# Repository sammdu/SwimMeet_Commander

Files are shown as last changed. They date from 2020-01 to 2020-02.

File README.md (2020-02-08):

# Swim Meet Commander

#### Unofficial macro keyboard for the [HY-TEK Swim Meet Manager](https://hytek.active.com/swim-meet-software.html) software.   

Designed with [KiCad](https://www.kicad-pcb.org/)   
Programmed with [Arduino](https://www.arduino.cc/)   

<a rel="license" href="https://www.oshwa.org/definition/">Open Source Hardware</a>
&nbsp;&nbsp;


## What Is This

A macro keyboard that controls the swim meet scoring software commonly used in American high-school and college swim meets. It simplifies operation of the software by pulling out 13 most used functionalities as dedicated keys, achieving one-key operation.

The device works by triggering keyboard shortcuts compatible with the swim meet software when a corresponding button is pushed. It is automatically recognized by most operating systems as an HID keyboard with no additional drivers required.

> 🔗 [See Technical Documentation on GitHub Wiki](https://github.com/sammdu/SwimMeet_Commander/wiki/Technical-Documentation)

## Assembled Device In-Operation

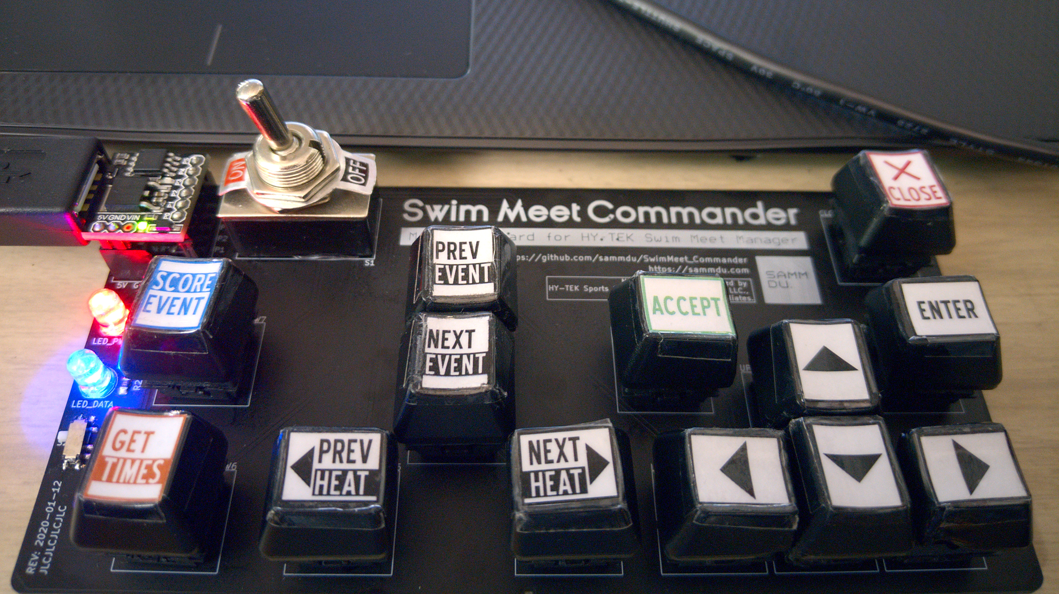
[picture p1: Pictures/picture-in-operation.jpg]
Assembled Device Picture


## 3D Renders

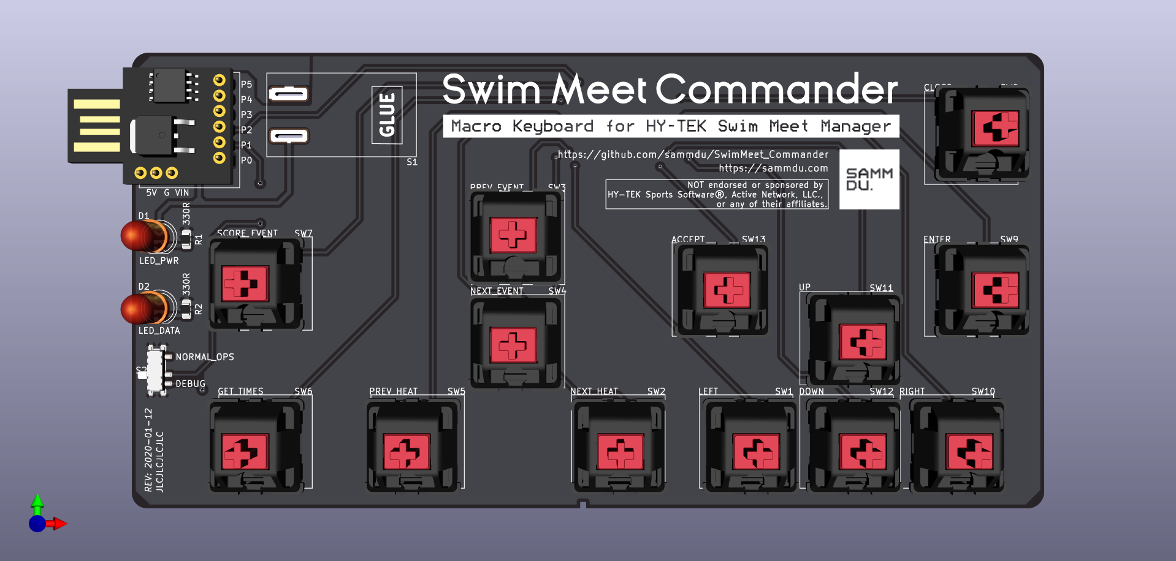
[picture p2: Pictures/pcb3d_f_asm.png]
PCB 3D Rendering, Front

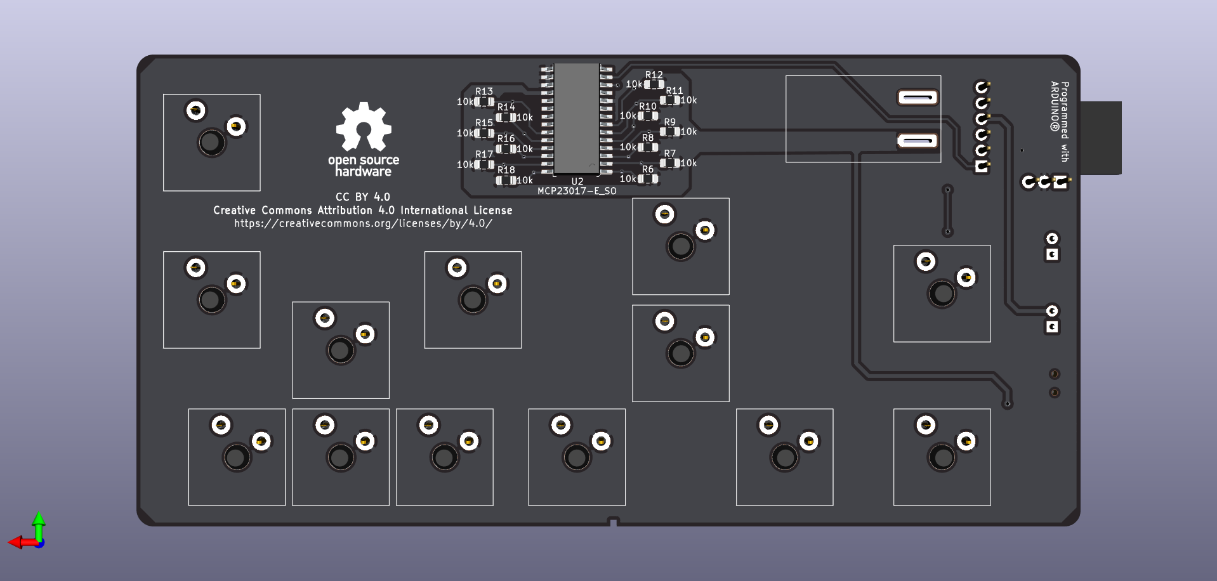
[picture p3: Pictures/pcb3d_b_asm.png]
PCB 3D Rendering, Back


## TODO

* adjust button spacing to account for keycaps

## Materials

* Microcontroller: Digispark Development Board - [Amazon Vendor](https://www.amazon.com/DAOKI-Digispark-Kickstarter-ATTINY85-Development/dp/B01MDUHSWO) | [Official Page (Out of Stock)](http://digistump.com/products/1)
* Printed Circuit Board (PCB) | [Get Gerber Production Files](https://github.com/sammdu/SwimMeet_Commander/tree/master/KiCad/Gerbers)
* I/O Expander (to support 13 switches simultaneously): [Microchip MCP23017](https://www.digikey.com/product-detail/en/MCP23017T-E%2fSO/MCP23017T-E%2fSOCT-ND/5358289/)
* Keyboard Switches: [E-Switch KS1100](https://www.digikey.com/product-detail/en/KS1100OA1AF060/EG5505-ND/7364301/)
* Key Caps: [Sparkfun PRT-15305](https://www.sparkfun.com/products/15305), or any Cherry MX compatible models   
* USB Male-Female Cable: [Qualtek 3021056-01M](https://www.digikey.com/product-detail/en/3021056-01M/Q1104-ND/7795306/), or any compatible USB Type-A cable   
* Toggle Switch: [Sparkfun COM-09276](https://www.sparkfun.com/products/9276)
* SMD Slide Switch: [Sparkfun COM-10860](https://www.sparkfun.com/products/10860), or any compatible models
* 5mm LEDs
* 0805 SMD Resistors: `330R`, `4k7` and `10k` values
* Pin Headers

## Copyright & Licensing

This project consists of open source software and hardware, released under [Creative Commons Attribution 4.0 International License](http://creativecommons.org/licenses/by/4.0/), unless otherwise specified.   

This project is NOT endorsed or sponsored by HY-TEK Sports Software®, Active Network, LLC., or any of their affiliates.

**NOTE:**
```
THE SCHEMATICS, DESIGN, SOURCE FILES, SOFTWARE, AND DATASHEETS ARE PROVIDED "AS IS",
WITHOUT WARRANTY OF ANY KIND, EXPRESS OR IMPLIED, INCLUDING BUT NOT LIMITED TO
THE WARRANTIES OF MERCHANTABILITY, FITNESS FOR A PARTICULAR PURPOSE AND
NONINFRINGEMENT. IN NO EVENT SHALL THE AUTHORS OR COPYRIGHT HOLDERS BE LIABLE FOR
ANY CLAIM, DAMAGES OR OTHER LIABILITY, WHETHER IN AN ACTION OF CONTRACT, TORT
OR OTHERWISE, ARISING FROM, OUT OF OR IN CONNECTION WITH THE SCHEMATICS, DESIGN,
SOURCE FILES, SOFTWARE, AND DATASHEETS OR THE USE OR OTHER DEALINGS IN THE
SCHEMATICS, DESIGN, SOURCE FILES, SOFTWARE, AND DATASHEETS.
 ```

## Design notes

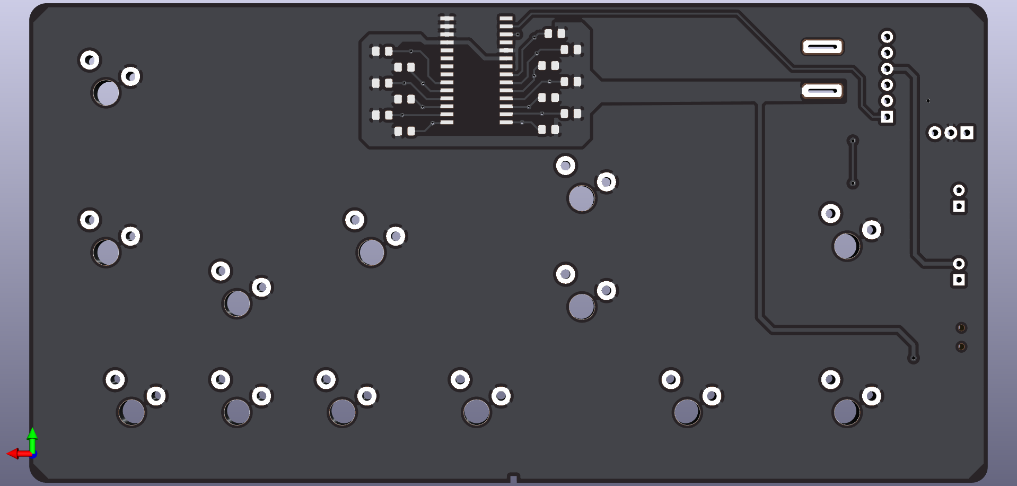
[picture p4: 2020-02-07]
Pictures/pcb3d_b_nosilk.png

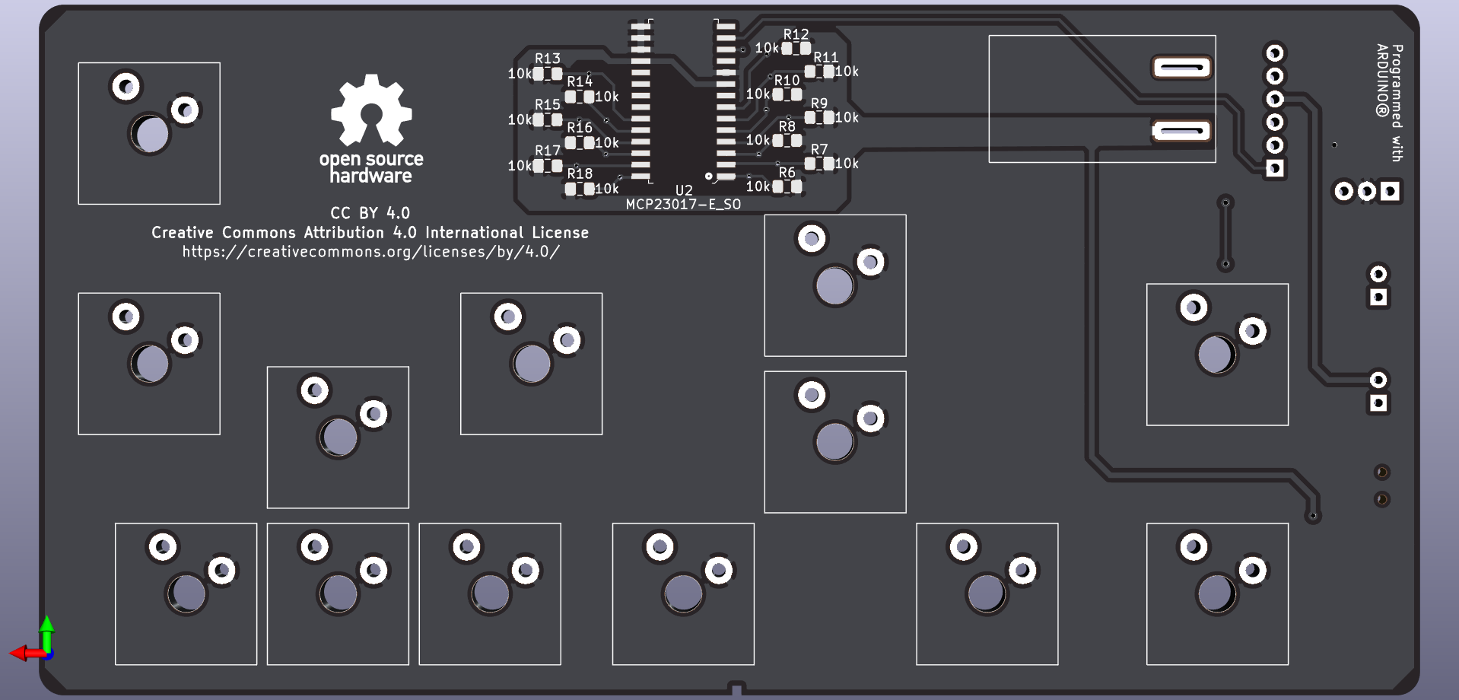
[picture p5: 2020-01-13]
Pictures/pcb3d_b.png

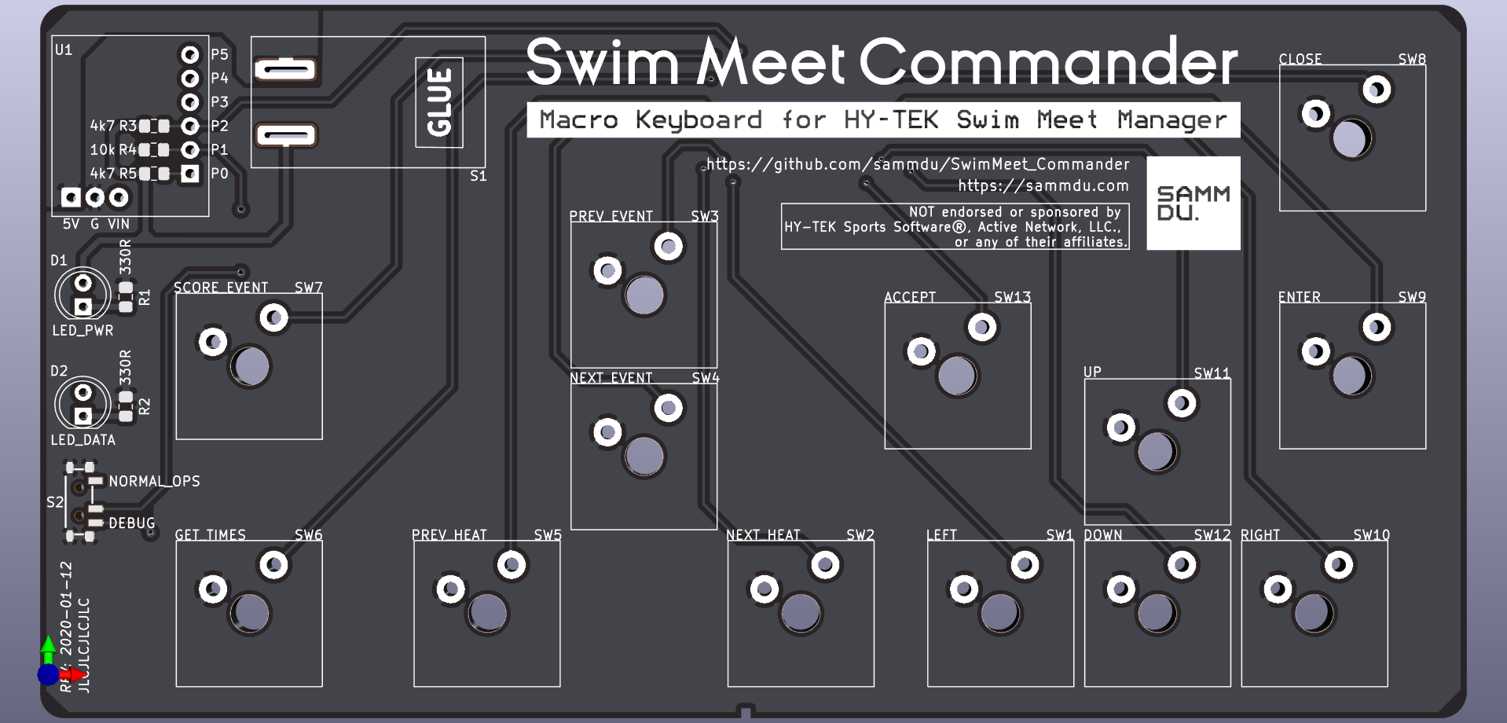
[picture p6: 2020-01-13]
Pictures/pcb3d_f.png

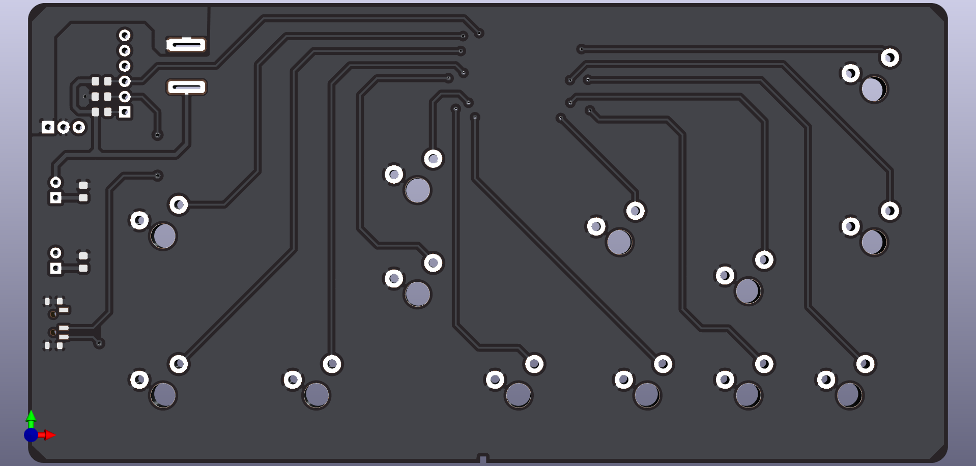
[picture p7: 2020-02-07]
Pictures/pcb3d_f_nosilk.png

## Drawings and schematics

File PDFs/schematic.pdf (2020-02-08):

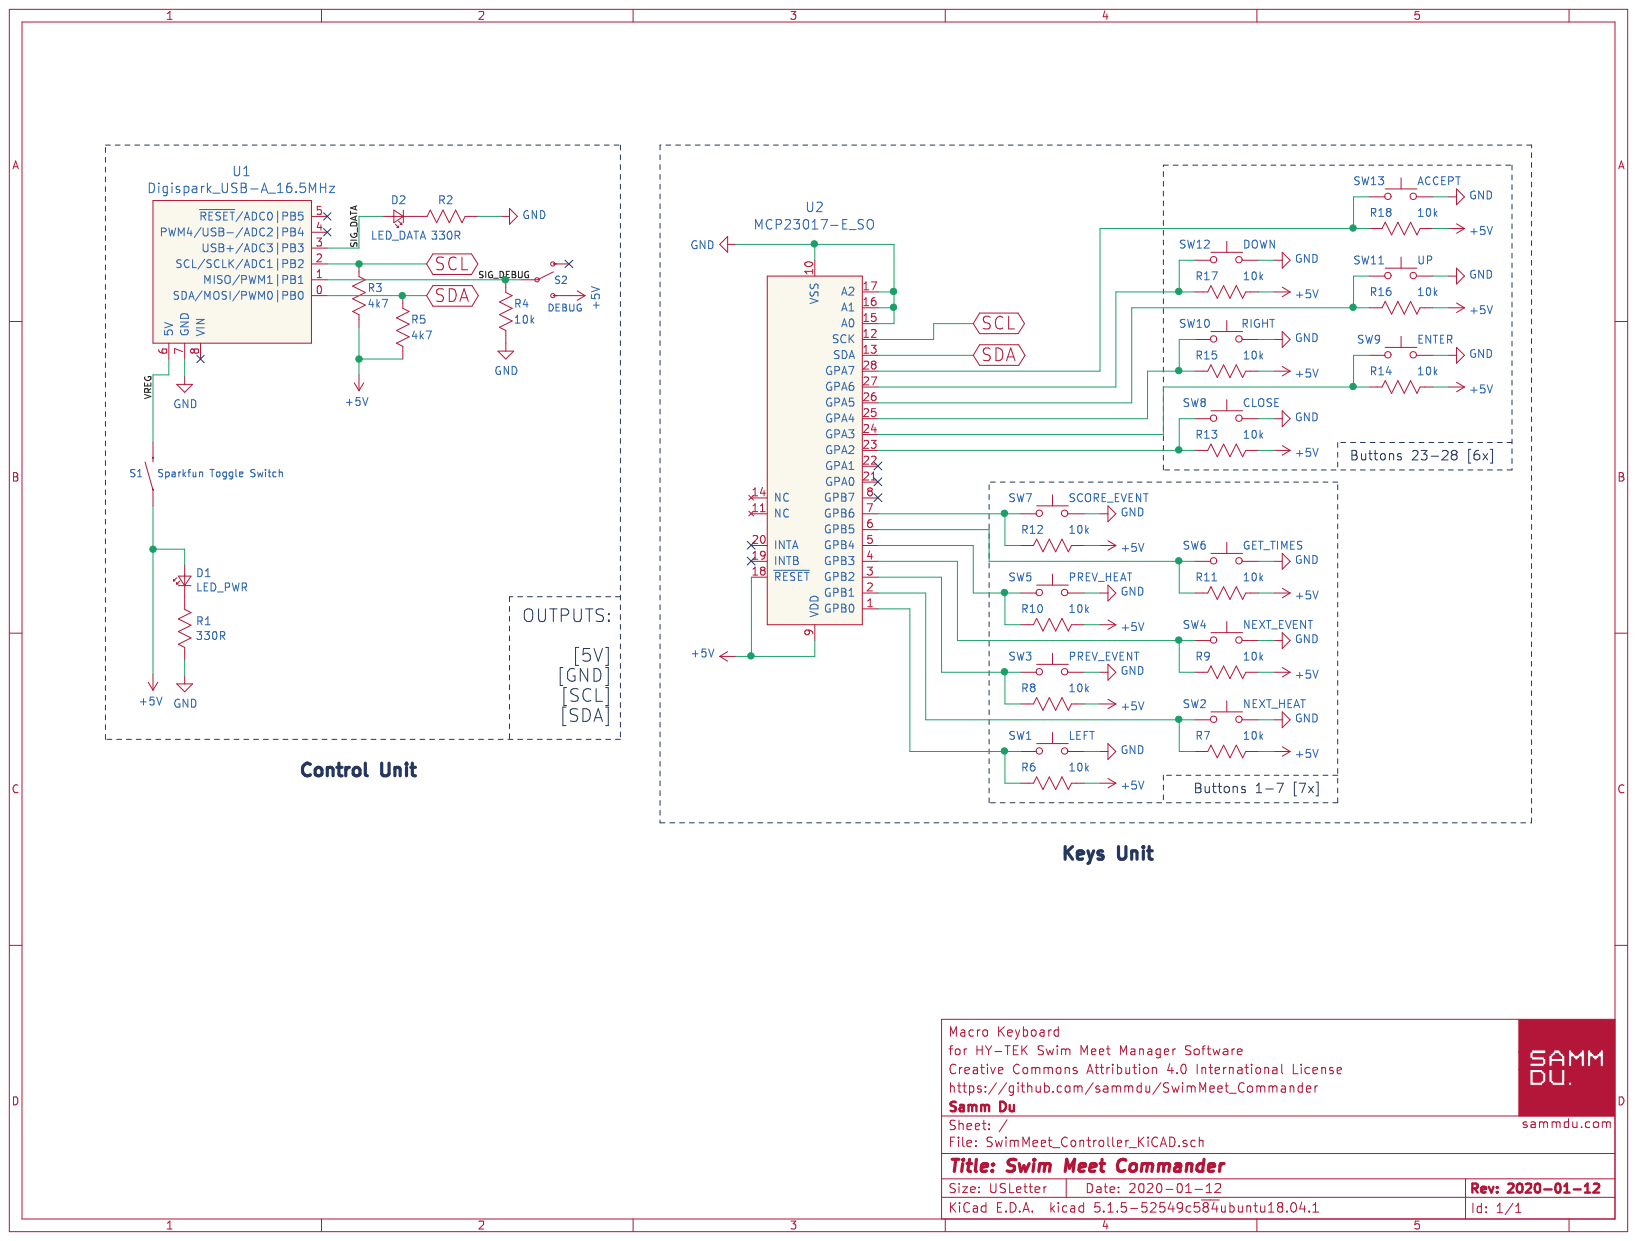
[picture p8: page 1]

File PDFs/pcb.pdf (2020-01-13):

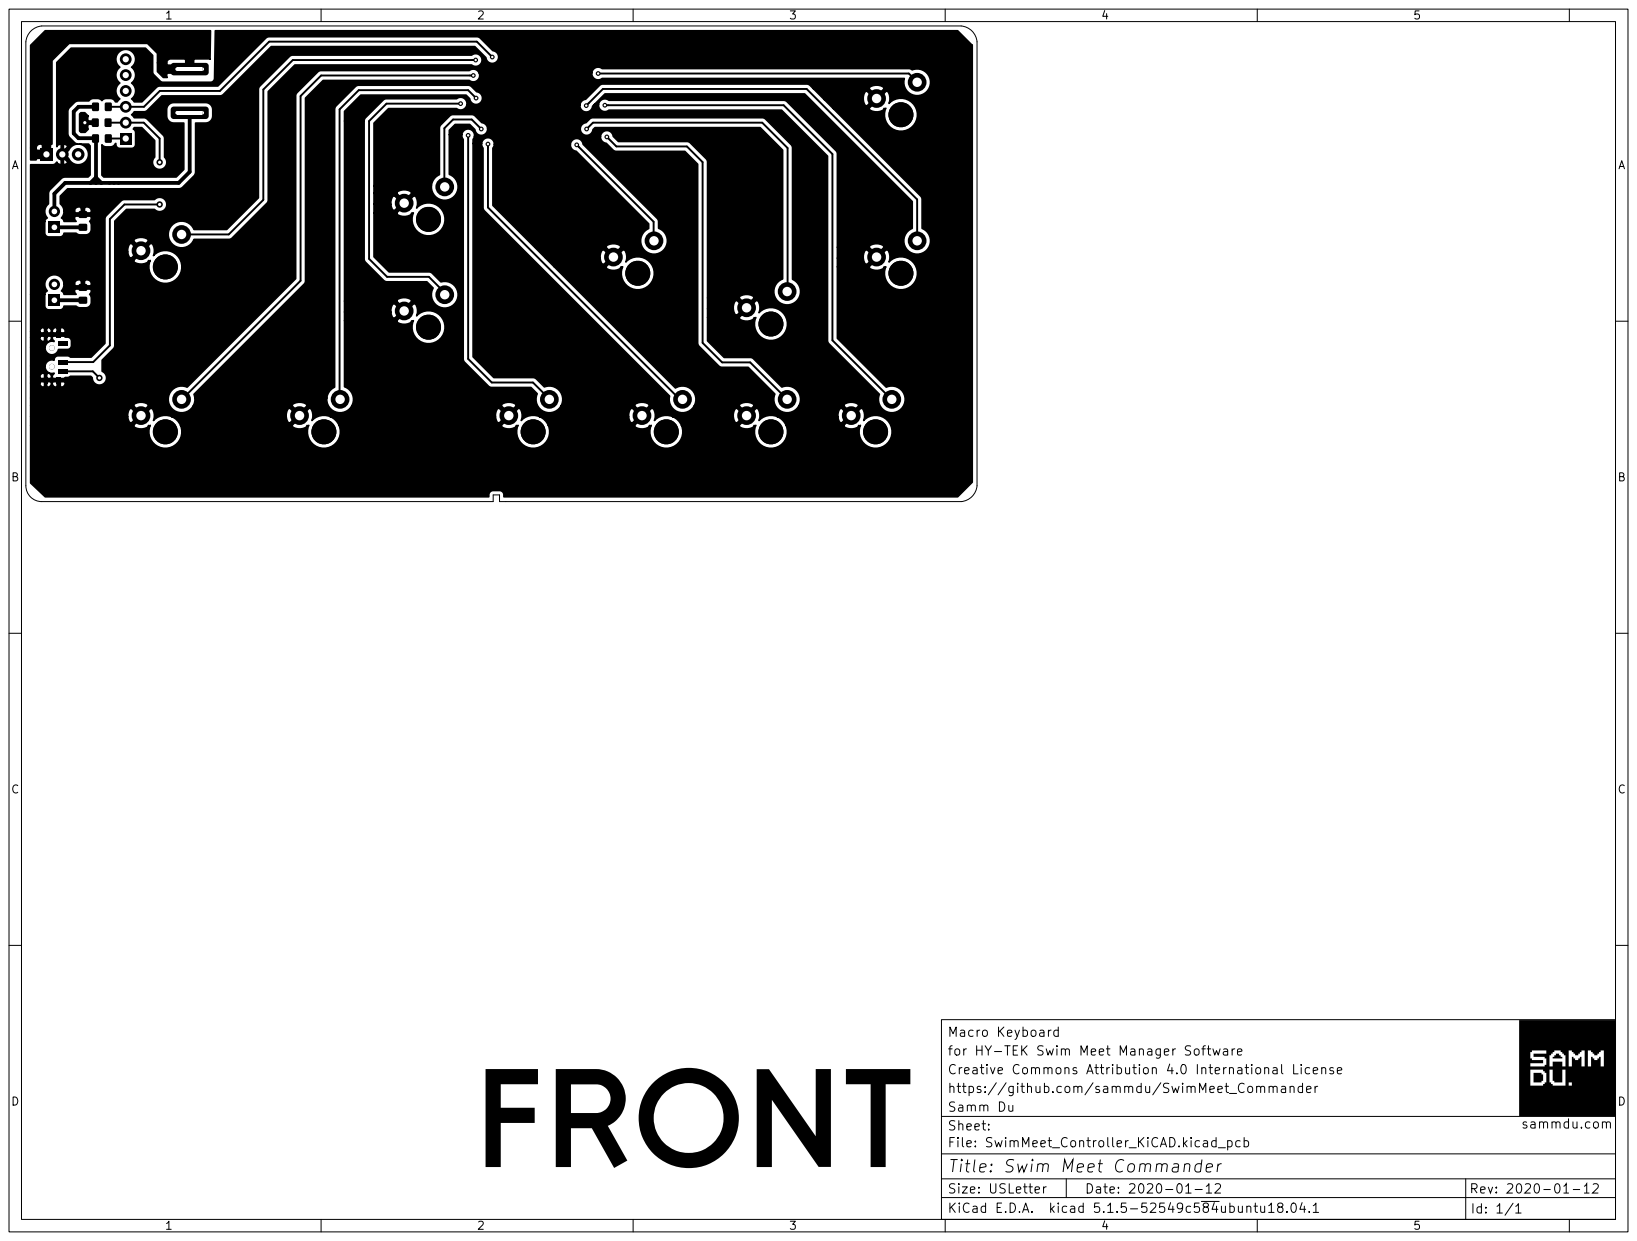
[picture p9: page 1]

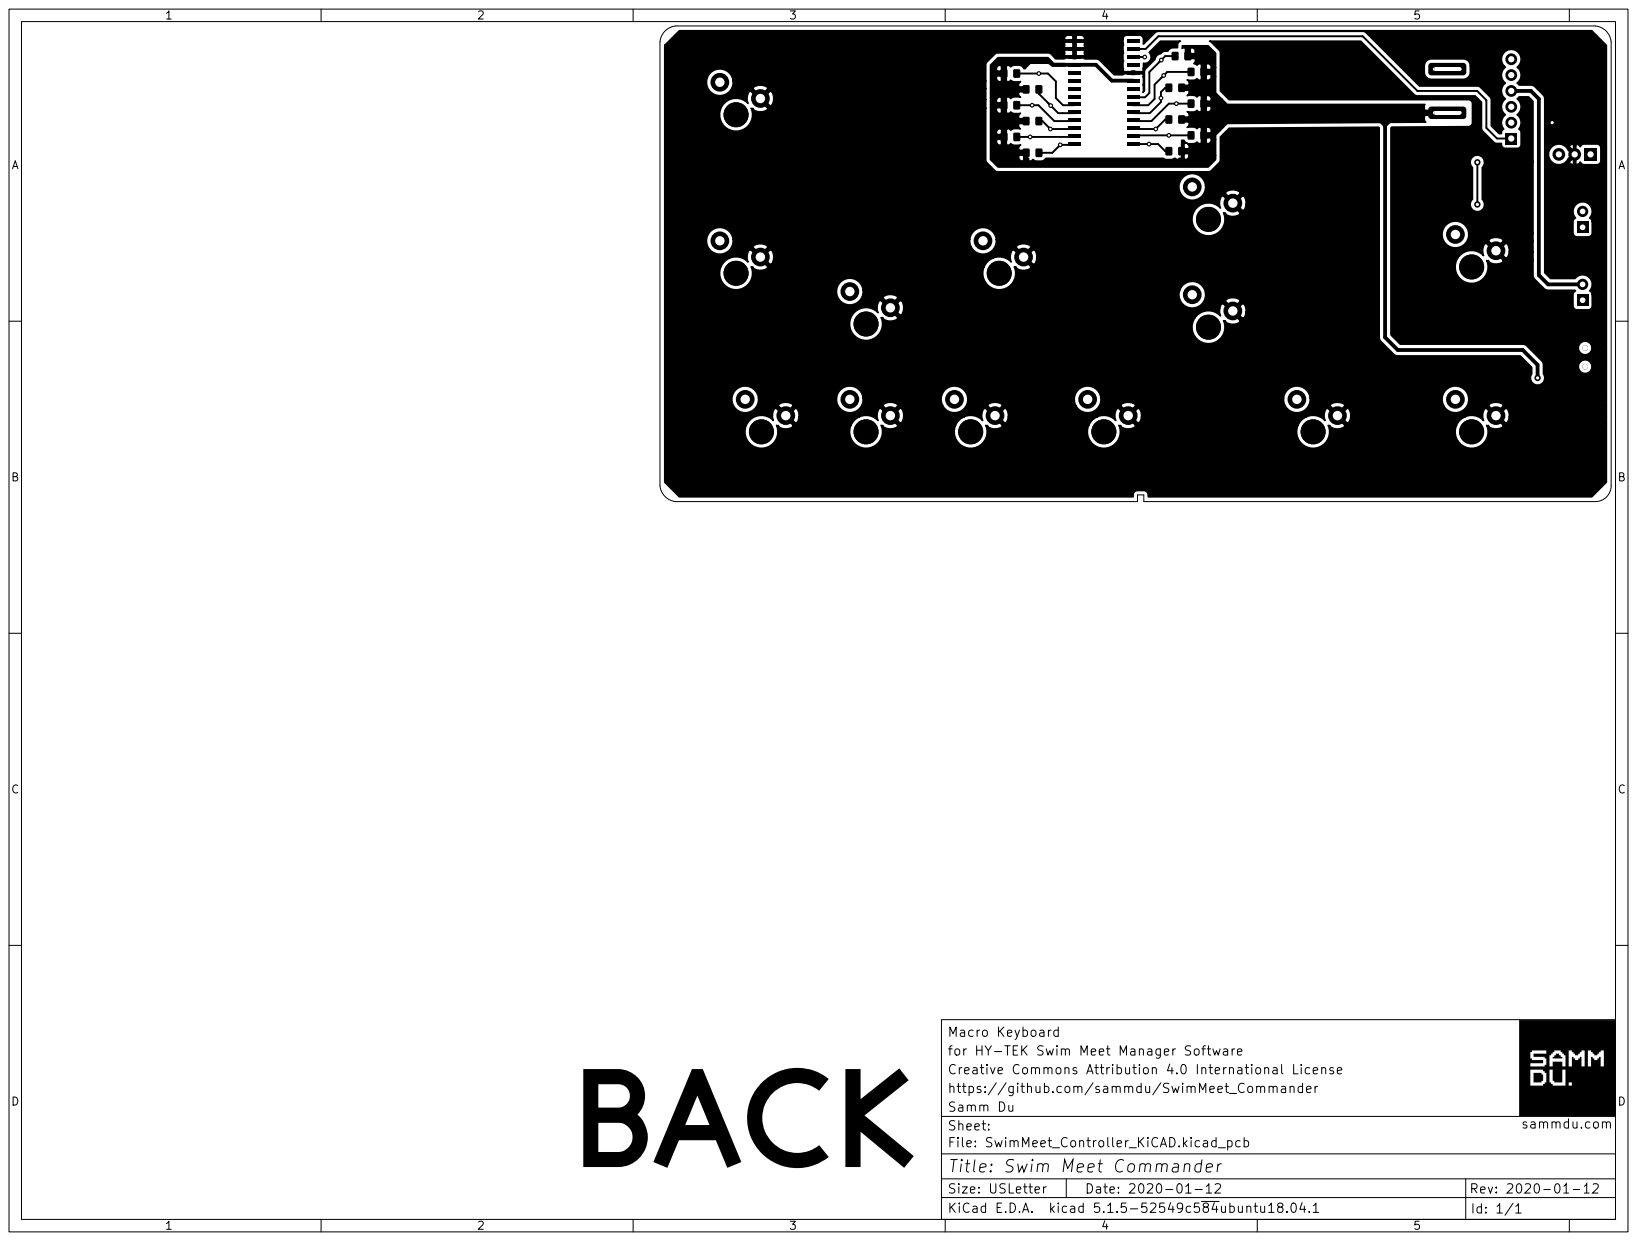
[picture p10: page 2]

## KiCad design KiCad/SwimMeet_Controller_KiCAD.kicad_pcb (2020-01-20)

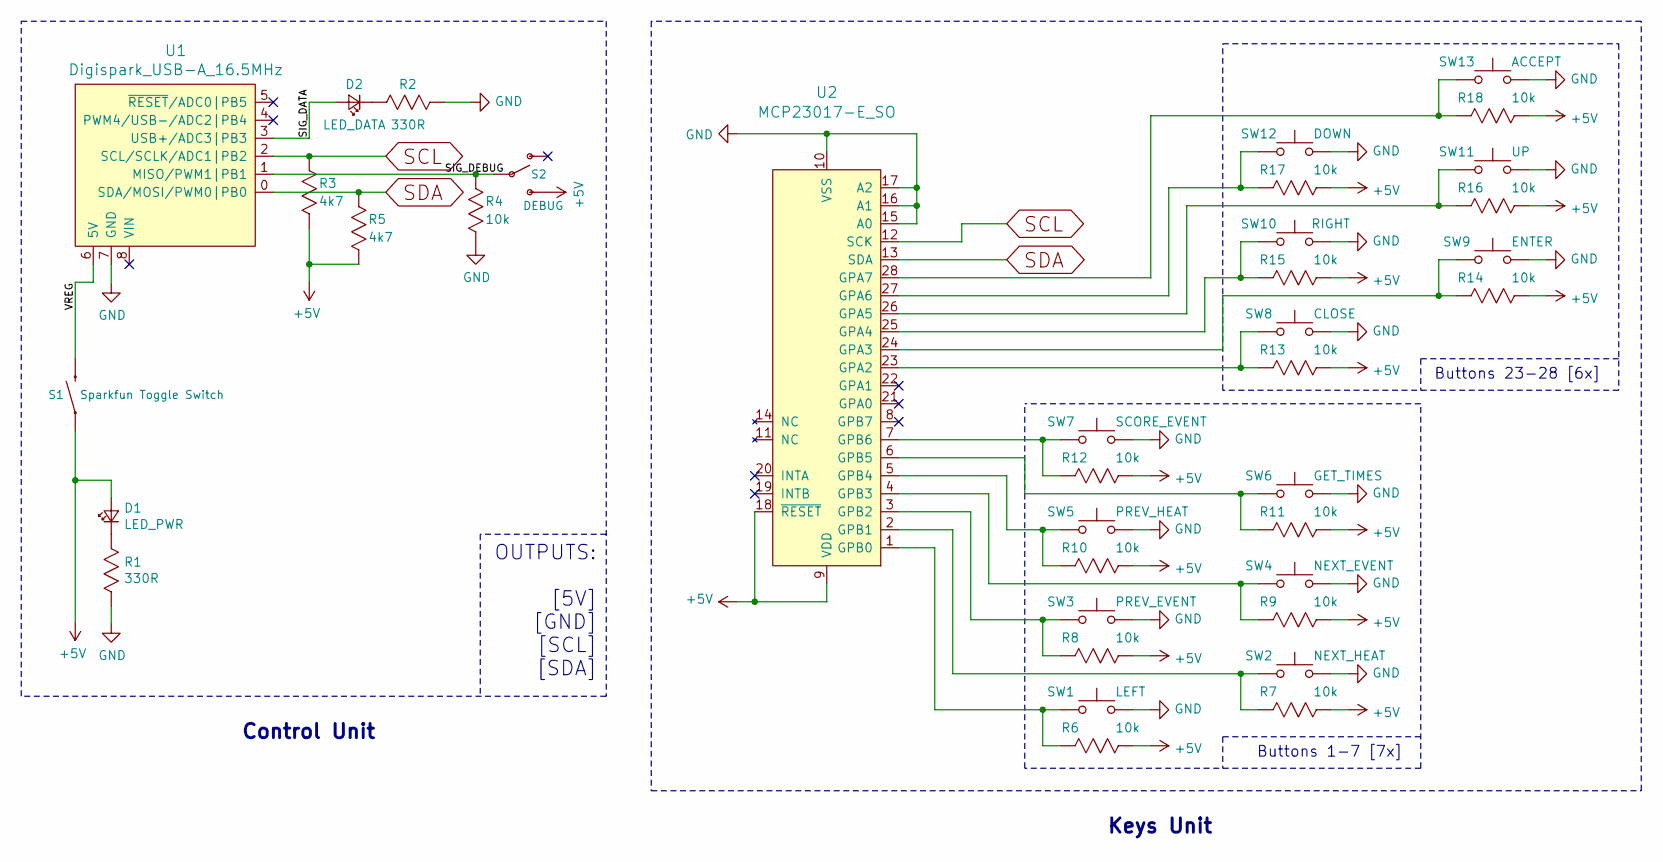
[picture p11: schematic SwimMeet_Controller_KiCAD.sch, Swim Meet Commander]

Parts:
D1: LED_PWR; LED_D5.0mm
D2: LED_DATA; LED_D5.0mm
R1, R2: 330R; R_0805_2012Metric_Pad1.15x1.40mm_HandSolder
R3, R5: 4k7; R_0805_2012Metric_Pad1.15x1.40mm_HandSolder
R4, R6, R7, R8, R9, R10, R11, R12, R13, R14, R15, R16, R17, R18: 10k; R_0805_2012Metric_Pad1.15x1.40mm_HandSolder
S1: Sparkfun Toggle Switch; TOGGLE_PANEL_COM-09276
S2: DEBUG; SWITCH_SPST_SMD_A
SW1: LEFT; SW_KeySwitch_KS1100_E-SWITCH
SW2: NEXT_HEAT; SW_KeySwitch_KS1100_E-SWITCH
SW3: PREV_EVENT; SW_KeySwitch_KS1100_E-SWITCH
SW4: NEXT_EVENT; SW_KeySwitch_KS1100_E-SWITCH
SW5: PREV_HEAT; SW_KeySwitch_KS1100_E-SWITCH
SW6: GET_TIMES; SW_KeySwitch_KS1100_E-SWITCH
SW7: SCORE_EVENT; SW_KeySwitch_KS1100_E-SWITCH
SW8: CLOSE; SW_KeySwitch_KS1100_E-SWITCH
SW9: ENTER; SW_KeySwitch_KS1100_E-SWITCH
SW10: RIGHT; SW_KeySwitch_KS1100_E-SWITCH
SW11: UP; SW_KeySwitch_KS1100_E-SWITCH
SW12: DOWN; SW_KeySwitch_KS1100_E-SWITCH
SW13: ACCEPT; SW_KeySwitch_KS1100_E-SWITCH
U1: Digispark_USB-A_16.5MHz; Digispark_USB-A
U2: MCP23017-E_SO; SOIC-28_W7.5mm; MPN MCP23017-E/SO; Digi-Key_PN MCP23017-E/SO-ND

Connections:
+5V: D1.2 (A), R3.2, R5.2, R6.1, R7.1, R8.1, R9.1, R10.1, R11.1, R12.1, R13.1, R14.1, R15.1, R16.1, R17.1, R18.1, S1.1, S2.3 (S), U2.9 (VDD), U2.18 (~RESET)
/SIG_DATA: D2.2 (A), U1.3 (USB+/ADC3|PB3)
/SIG_DEBUG: R4.1, S2.2, U1.1 (MISO/PWM1|PB1)
/VREG: S1.2, U1.6 (5V)
GND: R1.2, R2.2, R4.2, S2.GND1, S2.GND2, S2.GND3, S2.GND4, SW1.2, SW2.2, SW3.2, SW4.2, SW5.2, SW6.2, SW7.2, SW8.2, SW9.2, SW10.2, SW11.2, SW12.2, SW13.2, U1.7 (GND), U2.10 (VSS), U2.15 (A0), U2.16 (A1), U2.17 (A2)
unnamed: D1.1 (K), R1.1
unnamed: D2.1 (K), R2.1
unnamed: R6.2, SW1.1, U2.1 (GPB0)
unnamed: R7.2, SW2.1, U2.2 (GPB1)
unnamed: R8.2, SW3.1, U2.3 (GPB2)
unnamed: R9.2, SW4.1, U2.4 (GPB3)
unnamed: R10.2, SW5.1, U2.5 (GPB4)
unnamed: R11.2, SW6.1, U2.6 (GPB5)
unnamed: R12.2, SW7.1, U2.7 (GPB6)
unnamed: R13.2, SW8.1, U2.23 (GPA2)
unnamed: R14.2, SW9.1, U2.24 (GPA3)
unnamed: R15.2, SW10.1, U2.25 (GPA4)
unnamed: R16.2, SW11.1, U2.26 (GPA5)
unnamed: R17.2, SW12.1, U2.27 (GPA6)
unnamed: R18.2, SW13.1, U2.28 (GPA7)
SCL: R3.1, U1.2 (SCL/SCLK/ADC1|PB2), U2.12 (SCK)
SDA: R5.1, U1.0 (SDA/MOSI/PWM0|PB0), U2.13 (SDA)

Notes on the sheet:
OUTPUTS: [5V] [GND] [SCL] [SDA]
Buttons 1-7 [7x]
Buttons 23-28 [6x]
Control Unit
Keys Unit

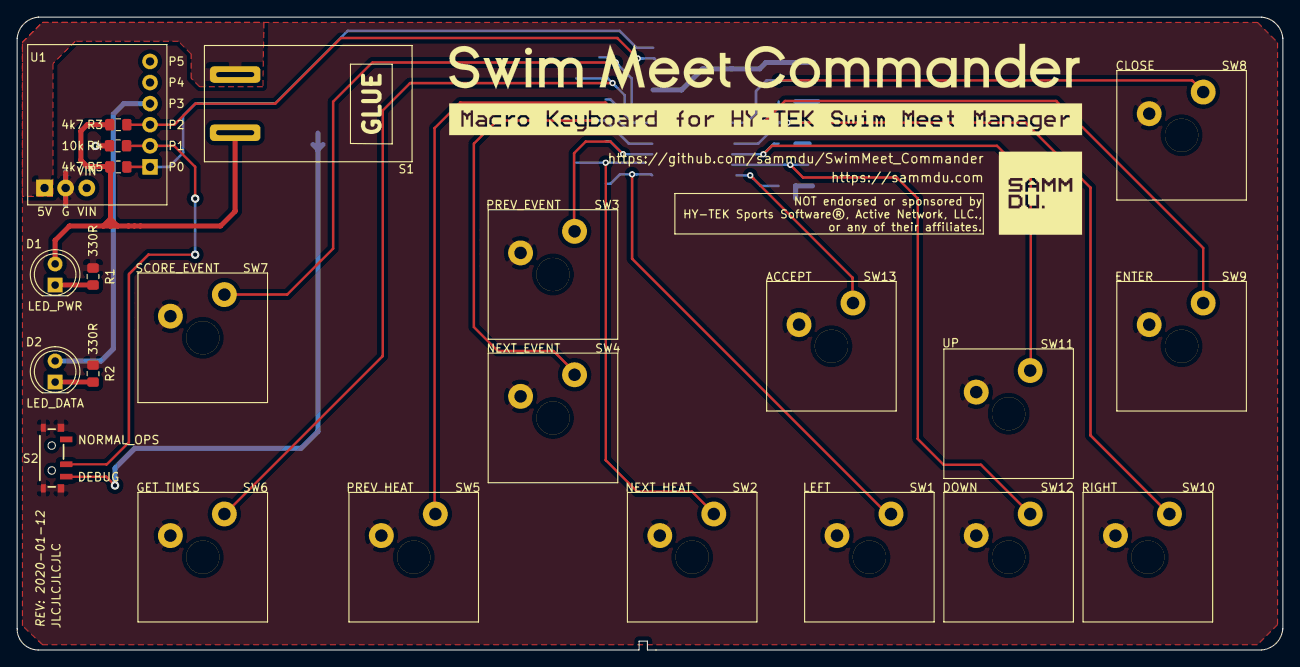
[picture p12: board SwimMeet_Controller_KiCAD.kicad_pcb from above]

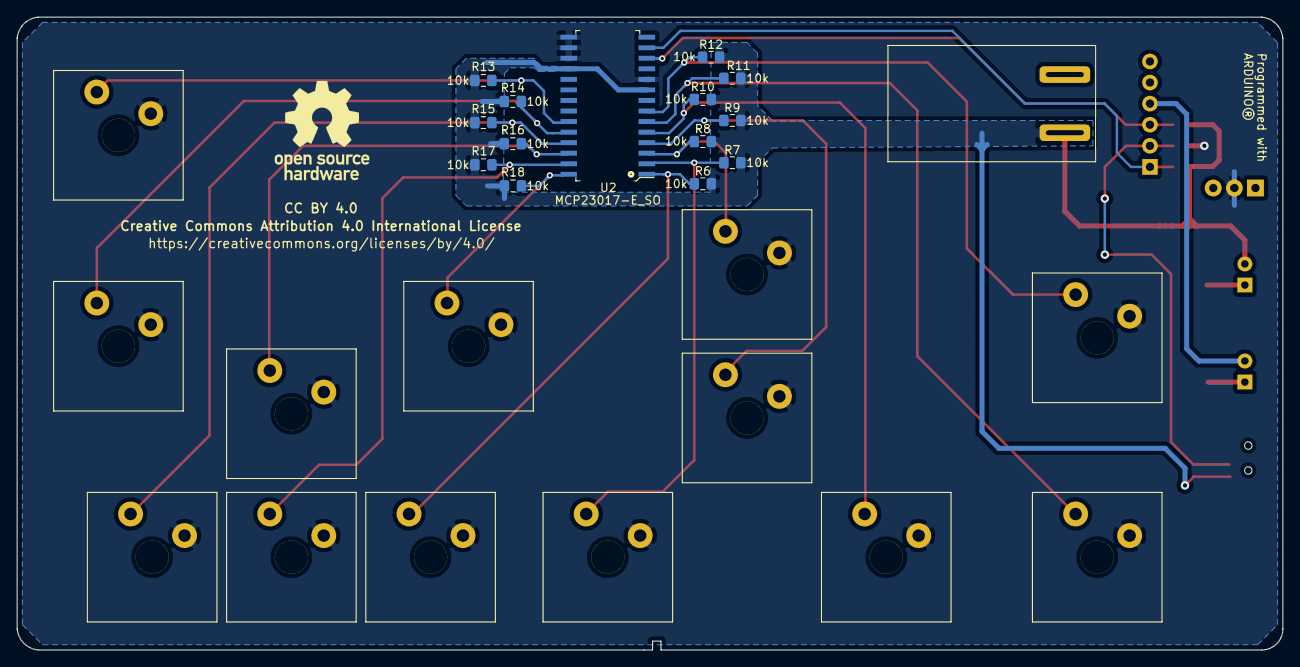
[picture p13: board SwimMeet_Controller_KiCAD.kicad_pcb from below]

Board: 2 copper layers, 152.4 x 76.2 mm, 37 parts (14 on the bottom side), 22 nets.

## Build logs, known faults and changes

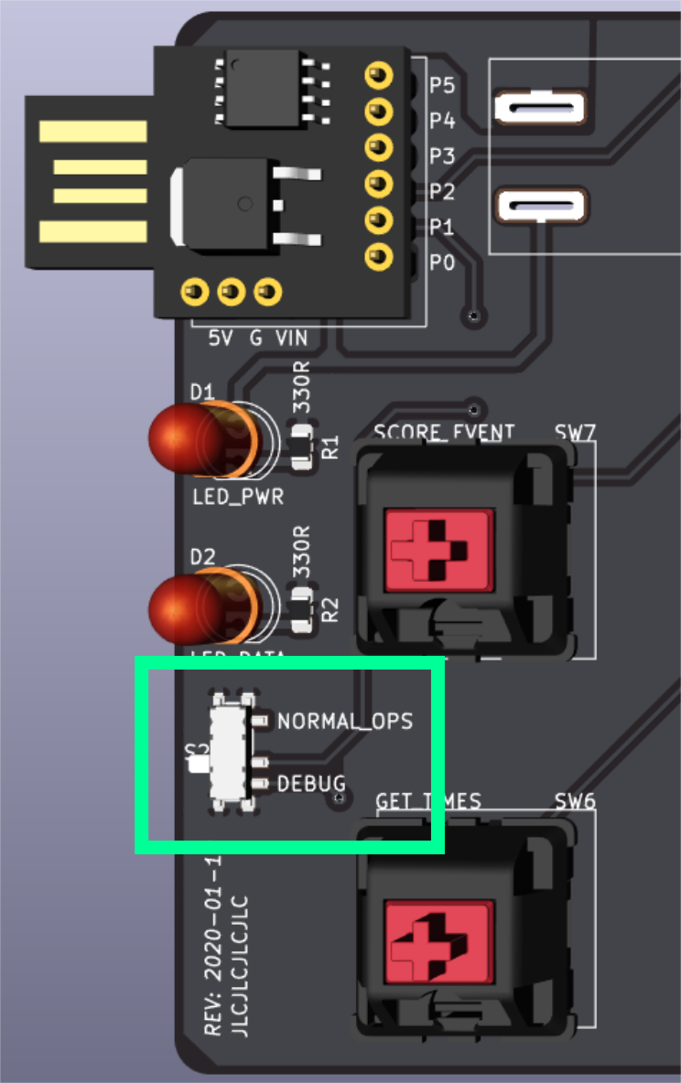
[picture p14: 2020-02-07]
Pictures/debug_switch_location.png

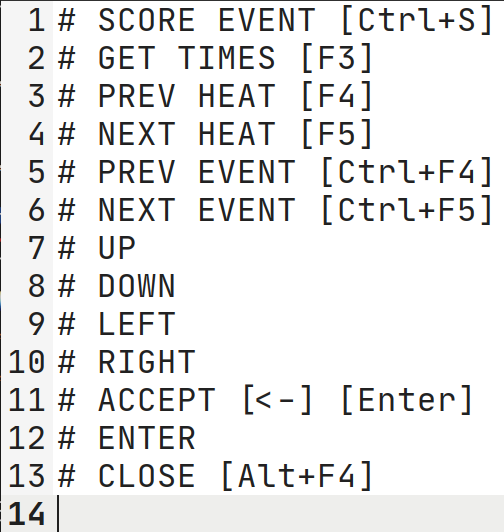
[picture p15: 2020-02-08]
Pictures/debug_output.png

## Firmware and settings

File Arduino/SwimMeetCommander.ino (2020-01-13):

#include "Wire.h"
#include "DigiKeyboard.h"

/*
    define undefined arrow key codes
    https://www.usb.org/sites/default/files/documents/hut1_12v2.pdf
*/
#define KEY_ARROW_UP    0x52
#define KEY_ARROW_DOWN  0x51
#define KEY_ARROW_RIGHT 0x4F

/* debug pin with external pull-down resistor */
int debug_pin = 1;
int debug_state; // debug mode is active HIGH

/* delay between two input readings */
int debounce_time = 170;

/* I/O expander state variables */
byte inputs_A = 1;
byte inputs_B = 1;

void setup()
{

  Wire.begin(); // wake up I2C bus

  DigiKeyboard.delay(50); // initialize keyboard transmission

  pinMode(debug_pin, INPUT); // initialize debug pin as input

}

void loop()
{

  /*
     this is generally not necessary but with some older systems
     it seems to prevent missing the first character after a delay
  */
  DigiKeyboard.sendKeyStroke(0);

  /* READ debug pin */
  debug_state = digitalRead(debug_pin);

  /* READ GPIO-A */
  Wire.beginTransmission(0x20);
  Wire.write(0x12);             // set MCP23017 memory pointer to GPIO-A address
  Wire.endTransmission();
  Wire.requestFrom(0x20, 1);    // request one byte of data from MCP20317
  inputs_A = Wire.read();       // store the incoming byte

  /* READ GPIO-B */
  Wire.beginTransmission(0x20);
  Wire.write(0x13);             // set MCP23017 memory pointer to GPIO-B address
  Wire.endTransmission();
  Wire.requestFrom(0x20, 1);    // request one byte of data from MCP20317
  inputs_B = Wire.read();       // store the incoming byte

  /*
      Poll Button States
  */

  /* SCORE EVENT */
  if (inputs_B == 0b10111111)
  {
    if (not debug_state)
    {
      // [Ctrl+S]
      DigiKeyboard.sendKeyStroke(KEY_S, MOD_CONTROL_LEFT);
      DigiKeyboard.delay(debounce_time);
    }
    else
    {
      DigiKeyboard.print("# SCORE EVENT [Ctrl+S]");
      DigiKeyboard.print("\n");
      DigiKeyboard.delay(debounce_time);
    }
  }

  /* GET TIMES */
  if (inputs_B == 0b11011111)
  {
    if (not debug_state)
    {
      // [F3]
      DigiKeyboard.sendKeyStroke(KEY_F3);
      DigiKeyboard.delay(debounce_time);
    }
    else
    {
      DigiKeyboard.print("# GET TIMES [F3]");
      DigiKeyboard.print("\n");
      DigiKeyboard.delay(debounce_time);
    }
  }

  /* PREV HEAT */
  if (inputs_B == 0b11101111)
  {
    if (not debug_state)
    {
      // [F4]
      DigiKeyboard.sendKeyStroke(KEY_F4);
      DigiKeyboard.delay(debounce_time);
    }
    else
    {
      DigiKeyboard.print("# PREV HEAT [F4]");
      DigiKeyboard.print("\n");
      DigiKeyboard.delay(debounce_time);
    }
  }

  /* NEXT HEAT */
  if (inputs_B == 0b11111101)
  {
    if (not debug_state)
    {
      // [F5]
      DigiKeyboard.sendKeyStroke(KEY_F5);
      DigiKeyboard.delay(debounce_time);
    }
    else
    {
      DigiKeyboard.print("# NEXT HEAT [F5]");
      DigiKeyboard.print("\n");
      DigiKeyboard.delay(debounce_time);
    }
  }

  /* PREV EVENT */
  if (inputs_B == 0b11111011)
  {
    if (not debug_state)
    {
      // [Ctrl+F4]
      DigiKeyboard.sendKeyStroke(KEY_F4, MOD_CONTROL_LEFT);
      DigiKeyboard.delay(debounce_time);
    }
    else
    {
      DigiKeyboard.print("# PREV EVENT [Ctrl+F4]");
      DigiKeyboard.print("\n");
      DigiKeyboard.delay(debounce_time);
    }
  }

  /* NEXT EVENT */
  if (inputs_B == 0b11110111)
  {
    if (not debug_state)
    {
      // [Ctrl+F5]
      DigiKeyboard.sendKeyStroke(KEY_F5, MOD_CONTROL_LEFT);
      DigiKeyboard.delay(debounce_time);
    }
    else
    {
      DigiKeyboard.print("# NEXT EVENT [Ctrl+F5]");
      DigiKeyboard.print("\n");
      DigiKeyboard.delay(debounce_time);
    }
  }

  /* UP */
  if (inputs_A == 0b11011111)
  {
    if (not debug_state)
    {
      // [Up]
      DigiKeyboard.sendKeyStroke(KEY_ARROW_UP);
      DigiKeyboard.delay(debounce_time);
    }
    else
    {
      DigiKeyboard.print("# UP");
      DigiKeyboard.print("\n");
      DigiKeyboard.delay(debounce_time);
    }
  }

  /* DOWN */
  if (inputs_A == 0b10111111)
  {
    if (not debug_state)
    {
      // [Down]
      DigiKeyboard.sendKeyStroke(KEY_ARROW_DOWN);
      DigiKeyboard.delay(debounce_time);
    }
    else
    {
      DigiKeyboard.print("# DOWN");
      DigiKeyboard.print("\n");
      DigiKeyboard.delay(debounce_time);
    }
  }

  /* LEFT */
  if (inputs_B == 0b11111110)
  {
    if (not debug_state)
    {
      // [Left]
      DigiKeyboard.sendKeyStroke(KEY_ARROW_LEFT);
      DigiKeyboard.delay(debounce_time);
    }
    else
    {
      DigiKeyboard.print("# LEFT");
      DigiKeyboard.print("\n");
      DigiKeyboard.delay(debounce_time);
    }
  }

  /* RIGHT */
  if (inputs_A == 0b11101111)
  {
    if (not debug_state)
    {
      // [Right]
      DigiKeyboard.sendKeyStroke(KEY_ARROW_RIGHT);
      DigiKeyboard.delay(debounce_time);
    }
    else
    {
      DigiKeyboard.print("# RIGHT");
      DigiKeyboard.print("\n");
      DigiKeyboard.delay(debounce_time);
    }
  }

  /* ACCEPT */
  if (inputs_A == 0b01111111)
  {
    if (not debug_state)
    {
      // [<-] (pause 30ms) [Enter]
      DigiKeyboard.sendKeyStroke(KEY_ARROW_LEFT);
      DigiKeyboard.delay(30);
      DigiKeyboard.sendKeyStroke(KEY_ENTER);
      DigiKeyboard.delay(debounce_time);
    }
    else
    {
      DigiKeyboard.print("# ACCEPT [<-] [Enter]");
      DigiKeyboard.print("\n");
      DigiKeyboard.delay(debounce_time);
    }
  }

  /* ENTER */
  if (inputs_A == 0b11110111)
  {
    if (not debug_state)
    {
      // [Enter]
      DigiKeyboard.sendKeyStroke(KEY_ENTER);
      DigiKeyboard.delay(debounce_time);
    }
    else
    {
      DigiKeyboard.print("# ENTER");
      DigiKeyboard.print("\n");
      DigiKeyboard.delay(debounce_time);
    }
  }

  /* CLOSE */
  if (inputs_A == 0b11111011)
  {
    if (not debug_state)
    {
      // [Alt+F4]
      DigiKeyboard.sendKeyStroke(KEY_F4, MOD_ALT_LEFT);
      DigiKeyboard.delay(debounce_time);
    }
    else
    {
      DigiKeyboard.print("# CLOSE [Alt+F4]");
      DigiKeyboard.print("\n");
      DigiKeyboard.delay(debounce_time);
    }
  }

}

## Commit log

2019-12-27 initial commit 2019-12-27
    [SwimMeet_Controller_KiCAD.kicad_pcb, SwimMeet_Controller_KiCAD.sch]
2019-12-27 added materials to README
2019-12-27 add KiCad credit to README
2019-12-28 used proper power symbols in schem; made schem compatible with larger grid size; added net names; tidy'ed up PCB more
    [SwimMeet_Controller_KiCAD.kicad_pcb, SwimMeet_Controller_KiCAD.sch]
2019-12-28 added toggle switch to materials in README
2019-12-28 updated PCB renders
2019-12-30 implemented polygons for 5V+ net
    [SwimMeet_Controller_KiCAD.kicad_pcb, SwimMeet_Controller_KiCAD.sch]
2020-01-01 improved power LED connection; updated front silk screen; updated titleblock
    [SwimMeet_Controller_KiCAD.kicad_pcb, SwimMeet_Controller_KiCAD.sch]
2020-01-03 added TODO item: debug switch
2020-01-08 adjusted resistor values, updated F.Silk graphic, updated toggle switch footprint
    [SwimMeet_Controller_KiCAD.kicad_pcb, SwimMeet_Controller_KiCAD.sch]
2020-01-09 updated resistor values in README
2020-01-13 MAJOR REVISION 2020-01-12
    [SwimMeet_Controller_KiCAD.kicad_pcb, SwimMeet_Controller_KiCAD.sch]
2020-01-13 restructured directory
    [SwimMeet_Controller_KiCAD.kicad_pcb, SwimMeet_Controller_KiCAD.sch]
2020-01-13 re-appended Gerbers and PDFs
2020-01-20 updated materials description
2020-01-20 updated Digispark 3D model and README image
    [SwimMeet_Controller_KiCAD.kicad_pcb]
2020-02-04 renamed the Pictures folder; included assembled in-operation picture
2020-02-07 amended schematic and added pictures for the wiki
2020-02-07 added picture of the debug switch location
2020-02-08 update schematic PDF and image
2020-02-08 include debug output sample screenshot

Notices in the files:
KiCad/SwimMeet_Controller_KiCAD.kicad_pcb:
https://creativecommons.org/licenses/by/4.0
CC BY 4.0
